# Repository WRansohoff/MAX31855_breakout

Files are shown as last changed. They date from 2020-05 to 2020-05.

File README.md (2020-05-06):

# MAX31855 Thermocouple Amplifier Board

This is a simple breakout board for a `MAX31855` thermocouple amplifier. It is an easy-to-use chip which handles all of the fancy math and analog conversion for calculating the temperature output from a thermocouple.

Need to measure temperatures higher than a couple hundred degrees C? Give one of these a try.

See `max31855_BOM.csv` for a bill of materials, but the only oddly-sized part is the screw terminal block.

See `firmware/` for an example STM32 program which reads the currently detected temperature value out of the chip if one is connected.

# Board Renders:

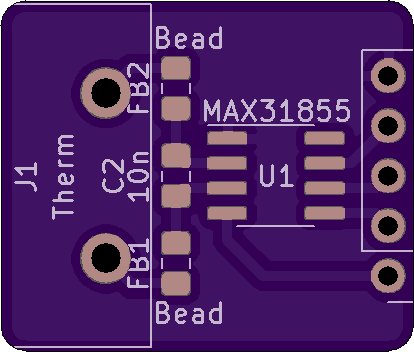
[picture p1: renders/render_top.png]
Board Top

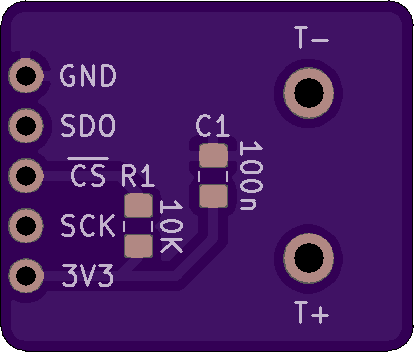
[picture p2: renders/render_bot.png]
Board Bottom


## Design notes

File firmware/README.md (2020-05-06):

# MAX31855 Thermocouple Amplifier Test Program

This is a simple application demonstrating how to read temperature data from a thermocouple using a `MAX31855` chip using an `STM32L432KC` microcontroller:

https://datasheets.maximintegrated.com/en/ds/MAX31855.pdf

The `MAX31855` outputs data over `SPI`, but it doesn't have a 'data in' pin. It outputs 32 bits of data when its `CS` pin is pulled low and the clock pin is toggled:

| Bit(s) | Meaning |
|:---:|:---:|
| 31 | Thermocouple temperature sign bit |
| 18-30  | Thermocouple temperature data |
| 17 | Reserved |
| 16 | 0 = reading okay, 1 = fault |
| 15 | Internal temperature sign bit |
| 4-14 | Internal temperature data |
| 3 | Reserved |
| 2 | 1 = short to `VCC` fault |
| 1 | 1 = short to `GND` fault |
| 0 | 1 = open circuit fault |

The last 16 bits contain diagnostics data, so you don't need to read them. This program only retrieves the first 16 bits to report temperature data and check that the chip didn't encounter a fault.

Be sure to use the right version of chip for your thermocouple! The `MAX31855KASA+` goes with K-type thermocouples, the `MAX31855NASA+` with N-type thermocouples, etc.

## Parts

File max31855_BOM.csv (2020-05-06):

Part ID | Part type | Part size | Part value | Example Digikey Item | Cost
C1 | Capacitor | 0805 | 100nF | https://www.digikey.com/short/zz0pb1 | $0.10
C2 | Capacitor | 0805 | 10nF | https://www.digikey.com/short/zz0p5q | $0.10
FB1, FB2 | Ferrite Bead | 0805 | Generic Filtering | https://www.digikey.com/short/zz0p59 | $0.20
J1 | Screw Terminal | 3/8" | 1x2 | https://www.digikey.com/short/zz0pb2 | $0.83
R1 | Resistor | 0805 | 10KΩ | https://www.digikey.com/short/zz0p5f | $0.10
U1 | Thermocouple Amplifier | SOIC-8 | MAX31855 | https://www.digikey.com/short/zz0pmp | $5.31
Total | - | - | - | - | $6.64

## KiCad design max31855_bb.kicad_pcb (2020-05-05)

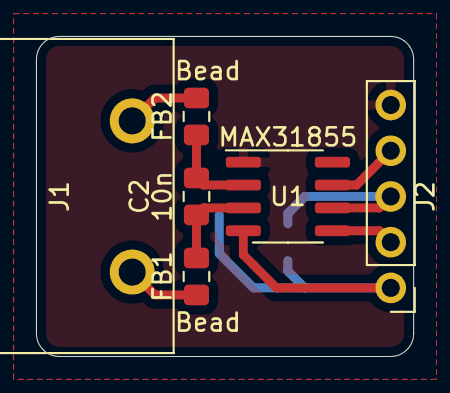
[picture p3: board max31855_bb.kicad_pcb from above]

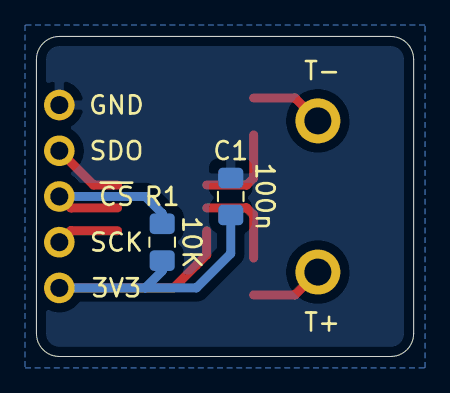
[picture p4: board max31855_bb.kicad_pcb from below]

Board: 2 copper layers, 21.0 x 17.8 mm, 8 parts (2 on the bottom side), 9 nets.

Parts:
C1: 100n; C_0805_2012Metric_Pad1.15x1.40mm_HandSolder
C2: 10n; C_0805_2012Metric_Pad1.15x1.40mm_HandSolder
FB1, FB2: Bead; R_0805_2012Metric_Pad1.15x1.40mm_HandSolder
J1: Therm; OSTYK42102030
J2: Breakout; PinHeader_1x05_P2.54mm_Vertical
R1: 10K; R_0805_2012Metric_Pad1.15x1.40mm_HandSolder
U1: MAX31855; SOIC-8_3.9x4.9mm_P1.27mm

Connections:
CK: J2.2, U1.5
DO: J2.4, U1.7
GND: C1.2, J2.5, U1.1
unnamed: C2.1, FB2.1, U1.2
unnamed: C2.2, FB1.1, U1.3
unnamed: FB1.2, J1.2
unnamed: FB2.2, J1.1
VCC: C1.1, J2.1, R1.1, U1.4
~CS: J2.3, R1.2, U1.6

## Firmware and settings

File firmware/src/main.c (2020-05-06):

#include "main.h"

// Default system clock frequency.
uint32_t core_clock_hz = 4000000;
// SysTick delay counter.
volatile uint32_t systick = 0;

// Reset handler: set the stack pointer and branch to main().
__attribute__( ( naked ) ) void reset_handler( void ) {
  // Set the stack pointer to the 'end of stack' value.
  __asm__( "LDR r0, =_estack\n\t"
           "MOV sp, r0" );
  // Branch to main().
  __asm__( "B main" );
}

// Delay for a specified number of milliseconds.
// TODO: Prevent rollover bug on the 'systick' value.
void delay_ms( uint32_t ms ) {
  // Calculate the 'end of delay' tick value, then wait for it.
  uint32_t next = systick + ms;
  while ( systick < next ) { __asm__( "WFI" ); }
}

// Override the 'write' clib method to implement 'printf' over UART.
int _write( int handle, char* data, int size ) {
  int count = size;
  while( count-- ) {
    while( !( USART2->ISR & USART_ISR_TXE ) ) {};
    USART2->TDR = *data++;
  }
  return size;
}

// Receive two bytes of data over SPI (blocking)
uint16_t spi_r16( SPI_TypeDef *SPIx ) {
  // Transmit two dummy bytes.
  while ( !( SPIx->SR & SPI_SR_TXE ) ) {};
  SPIx->DR = 0xFFFF;
  // Wait to receive data, then return it.
  while( !( SPIx->SR & SPI_SR_RXNE ) ) {};
  return SPIx->DR;
}

/**
 * Main program.
 */
int main(void) {
  // Copy initialized data from .sidata (Flash) to .data (RAM)
  memcpy( &_sdata, &_sidata, ( ( void* )&_edata - ( void* )&_sdata ) );
  // Clear the .bss section in RAM.
  memset( &_sbss, 0x00, ( ( void* )&_ebss - ( void* )&_sbss ) );

  // Enable floating-point unit.
  SCB->CPACR    |=  ( 0xF << 20 );

  // Use the 16MHz HSI oscillator for the system core clock.
  RCC->CR |=  ( RCC_CR_HSION );
  while ( !( RCC->CR & RCC_CR_HSIRDY ) ) {};
  RCC->CFGR &= ~( RCC_CFGR_SW );
  RCC->CFGR |=  ( RCC_CFGR_SW_HSI );
  while ( ( RCC->CFGR & RCC_CFGR_SWS ) != RCC_CFGR_SWS_HSI ) {};
  core_clock_hz = 16000000;

  // Setup the SysTick peripheral to generate 1ms ticks.
  SysTick_Config( core_clock_hz / 1000 );

  // Enable peripheral clocks: GPIOA, GPIOB, SPI1, USART2.
  RCC->APB1ENR1 |= ( RCC_APB1ENR1_USART2EN );
  RCC->APB2ENR  |= ( RCC_APB2ENR_SPI1EN );
  RCC->AHB2ENR  |= ( RCC_AHB2ENR_GPIOAEN |
                     RCC_AHB2ENR_GPIOBEN );

  // UART virtual COM port TX pin setup (AF7).
  GPIOA->MODER    &= ~( 0x3 << ( 2 * 2 ) );
  GPIOA->MODER    |=  ( 0x2 << ( 2 * 2 ) );
  GPIOA->OTYPER   &= ~( 0x1 << 2 );
  GPIOA->OSPEEDR  &= ~( 0x3 << ( 2 * 2 ) );
  GPIOA->OSPEEDR  |=  ( 0x2 << ( 2 * 2 ) );
  GPIOA->AFR[ 0 ] &= ~( 0xF << ( 2 * 4 ) );
  GPIOA->AFR[ 0 ] |=  ( 0x7 << ( 2 * 4 ) );

  // SPI pins setup.
  // PA11: software-controlled CS pin.
  GPIOA->MODER    &= ~( 0x3 << ( 11 * 2 ) );
  GPIOA->MODER    |=  ( 0x1 << ( 11 * 2 ) );
  GPIOA->OTYPER   &= ~( 0x1 << 11 );
  GPIOA->OSPEEDR  &= ~( 0x3 << ( 11 * 2 ) );
  GPIOA->OSPEEDR  |=  ( 0x1 << ( 11 * 2 ) );
  GPIOA->ODR      |=  ( 0x1 << 11 );
  // PB3, PB4: hardware-controlled SPI SCK/MISO pins (AF5).
  GPIOB->MODER    &= ~( ( 0x3 << ( 3 * 2 ) ) |
                        ( 0x3 << ( 4 * 2 ) ) );
  GPIOB->MODER    |=  ( ( 0x2 << ( 3 * 2 ) ) |
                        ( 0x2 << ( 4 * 2 ) ) );
  GPIOB->OSPEEDR  &= ~( ( 0x3 << ( 3 * 2 ) ) |
                        ( 0x3 << ( 4 * 2 ) ) );
  GPIOB->OSPEEDR  |=  ( ( 0x2 << ( 3 * 2 ) ) |
                        ( 0x2 << ( 4 * 2 ) ) );
  GPIOB->AFR[ 0 ] &= ~( ( 0xF << ( 3 * 4 ) ) |
                        ( 0xF << ( 4 * 4 ) ) );
  GPIOB->AFR[ 0 ] |=  ( ( 0x5 << ( 3 * 4 ) ) |
                        ( 0x5 << ( 4 * 4 ) ) );

  // USART2 setup: 115200 baud, transmit only.
  USART2->BRR  = ( core_clock_hz / 115200 );
  USART2->CR1 |= ( USART_CR1_TE | USART_CR1_UE );

  // SPI setup: standard host mode.
  SPI1->CR1 |= ( SPI_CR1_SSM |
                 SPI_CR1_SSI |
                 SPI_CR1_MSTR );
  SPI1->CR1 |= ( SPI_CR1_SPE );

  // Main loop: Read data every 5 seconds.
  uint16_t raw_data = 0x0000;
  float temp_c = 0.0;
  while( 1 ) {
    // Wait 5 seconds.
    delay_ms( 5000 );
    // Read data.
    GPIOA->ODR &= ~( 0x1 << 11 );
    raw_data = spi_r16( SPI1 );
    GPIOA->ODR |=  ( 0x1 << 11 );
    // Convert the raw output to big-endian format and print it.
    raw_data = ( raw_data << 8 ) | ( raw_data >> 8 );
    printf( "Raw temperature data: 0x%04X\r\n", raw_data );
    // If a fault was detected, report that.
    if ( raw_data & 0x0001 ) {
      printf( "FAULT\r\n" );
    }
    // Otherwise, calculate the temperature and print that.
    else {
      temp_c = ( ( raw_data & 0x7FFF ) >> 2 ) * 0.25;
      if ( raw_data & 0x8000 ) {
        temp_c = -temp_c;
      }
      printf( "Temperature: %.2fC, %.2fF\r\n",
              temp_c, ( temp_c * 1.8 ) + 32 );
    }
  }
}

// SysTick interrupt handler: increment the global 'systick' value.
void SysTick_IRQn_handler( void ) {
  ++systick;
}

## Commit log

2020-05-05 Add the initial KiCAD project
    [max31855_bb.kicad_pcb, max31855_bb.sch]
2020-05-06 Add a bill of materials
    [max31855_BOM.csv]
2020-05-06 Add test program demonstrating how to read temperature data from the chip.
2020-05-06 Don't configure the MOSI pin; it isn't used
2020-05-06 Add PCB renders
